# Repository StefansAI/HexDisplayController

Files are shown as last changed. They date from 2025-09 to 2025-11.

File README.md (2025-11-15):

<h1 style="text-align: center;">HexDisplayController</h1>
<h2 style="text-align: center;">A hexadecimal display module for TTL designs</h2>
<br>
<div style="text-align: center;">
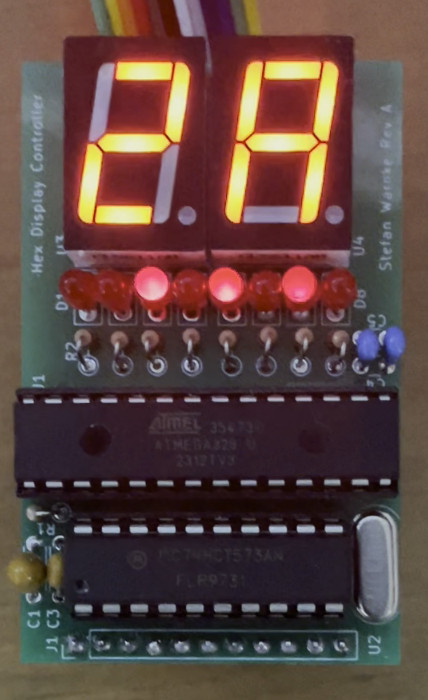
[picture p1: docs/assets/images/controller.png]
  
</div>
<br>
This small PCB reads an 8-bit input and converts the binary code to a 2 digit 7-segment LED as hexadecimals and 8 single bit LEDs. An input register can capture and hold the input data.
<br><br>
<div style="text-align: center;">
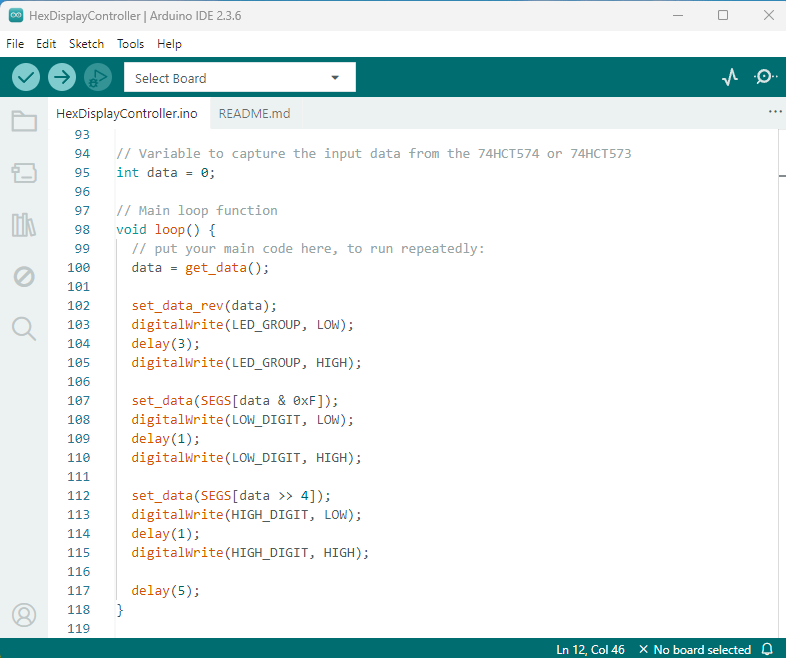
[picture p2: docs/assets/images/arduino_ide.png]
  
</div>
<br>
The processor had been programmed on an Arduino Uno R3 board and then plugged into this controller. 
<br><br>
<div style="text-align: center;">
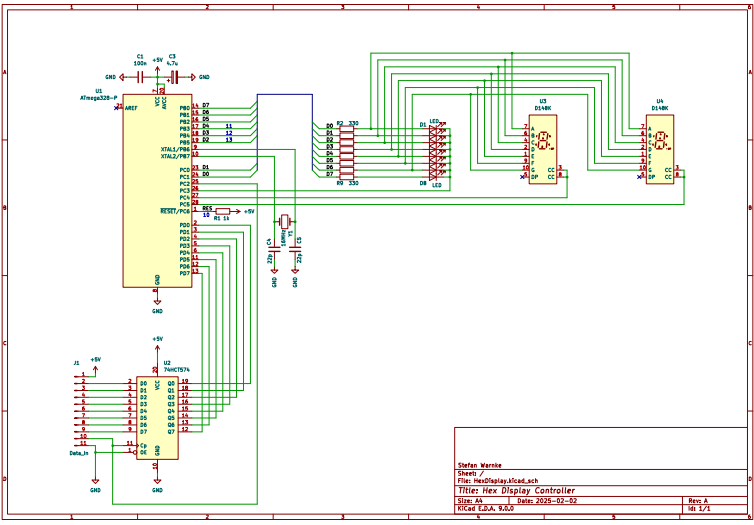
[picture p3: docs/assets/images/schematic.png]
  
</div>
<br>
The schematic and layout are design in KiCad 9 and the design files are included in the repository.
<br><br>
<div style="text-align: center;">
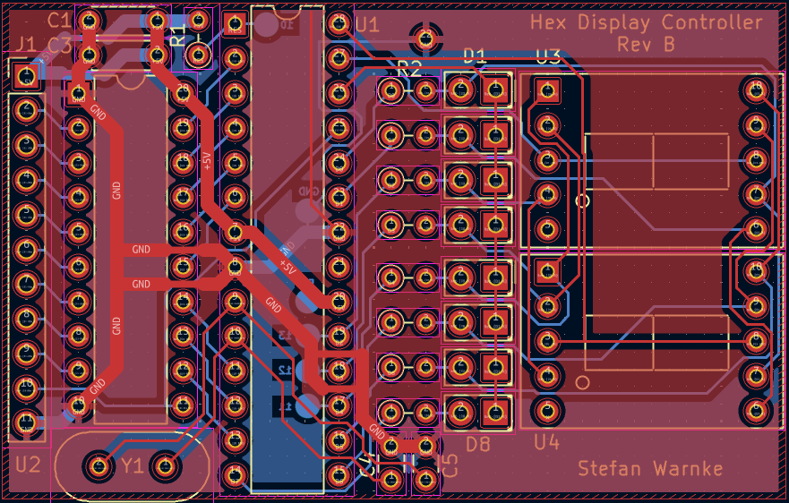
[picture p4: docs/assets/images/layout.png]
  
</div>
<br>
<br><br>
The PCB had been made at <a href="www.PCBway.com">PCBway.</a>

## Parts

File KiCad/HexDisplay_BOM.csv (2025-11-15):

Reference | Value | Datasheet | Footprint | Qty | DNP | OrderInfo
C1 | 100n | ~ | Capacitor_THT:C_Disc_D4.3mm_W1.9mm_P5.00mm | 1 |  | https://www.digikey.com/en/products/detail/kemet/C320C104M5R5TA/3726028
C3 | 4.7u | ~ | Capacitor_THT:C_Disc_D4.3mm_W1.9mm_P5.00mm | 1 |  | https://www.digikey.com/en/products/detail/kyocera-avx/TAP475M010SCS/1472017
C4,C5 | 22p | ~ | Capacitor_THT:C_Disc_D3.0mm_W1.6mm_P2.50mm | 2 |  | https://www.digikey.com/en/products/detail/tdk-corporation/FG28C0G1H220JNT06/5803099
D1,D8 | LED | ~ | LED_THT:LED_D2.0mm_W4.8mm_H2.5mm_FlatTop | 2 |  | https://www.digikey.com/en/products/detail/w%C3%BCrth-elektronik/151031SS04000/4489979
D2,D3,D4,D5,D6,D7 | ~ | ~ | LED_THT:LED_D2.0mm_W4.8mm_H2.5mm_FlatTop | 6 |  | https://www.digikey.com/en/products/detail/w%C3%BCrth-elektronik/151031SS04000/4489979
J1 | Data_In | ~ | Connector_PinHeader_2.54mm:PinHeader_1x11_P2.54mm_Vertical | 1 |  | https://www.digikey.com/en/products/detail/harwin-inc/M20-9771146/3920928
R1,R2,R3,R4,R5,R6,R7,R8,R9 | 1k | ~ | Resistor_THT:R_Axial_DIN0204_L3.6mm_D1.6mm_P2.54mm_Vertical | 9 |  | https://www.digikey.com/en/products/detail/stackpole-electronics-inc/CF18JT1K00/1741612
U1 | ATmega328-P | http://ww1.microchip.com/downloads/en/DeviceDoc/ATmega328_P%20AVR%20MCU%20with%20picoPower%20Technology%20Data%20Sheet%2040001984A.pdf | Package_DIP:DIP-28_W7.62mm | 1 |  | https://www.digikey.com/en/products/detail/microchip-technology/ATMEGA328-PU/2271026
U2 | 74HCT574 | http://www.ti.com/lit/gpn/sn74HCT574 | Package_DIP:DIP-20_W7.62mm | 1 |  | https://www.digikey.com/en/products/detail/texas-instruments/CD74HCT574E/38721
U3,U4 | D148K | https://ia800903.us.archive.org/24/items/CTKD1x8K/Cromatek%20D168K.pdf | Display_7Segment:D1X8K | 2 |  | https://www.amazon.com/dp/B07GTQWF4R?ref=ppx_yo2ov_dt_b_fed_asin_title&th=1
Y1 | 16MHz | ~ | Crystal:Crystal_HC49-U_Vertical | 1 |  | https://www.digikey.com/en/products/detail/yic/16M20P2-49US/15648595
 | 1 | DIP-20_W7.62mm_Socket |  |  |  | https://www.digikey.com/en/products/detail/on-shore-technology-inc/ED20DT/4147598
 | 1 | DIP-28_W7.62mm_Socket |  |  |  | https://www.digikey.com/en/products/detail/on-shore-technology-inc/ED281DT/4147600

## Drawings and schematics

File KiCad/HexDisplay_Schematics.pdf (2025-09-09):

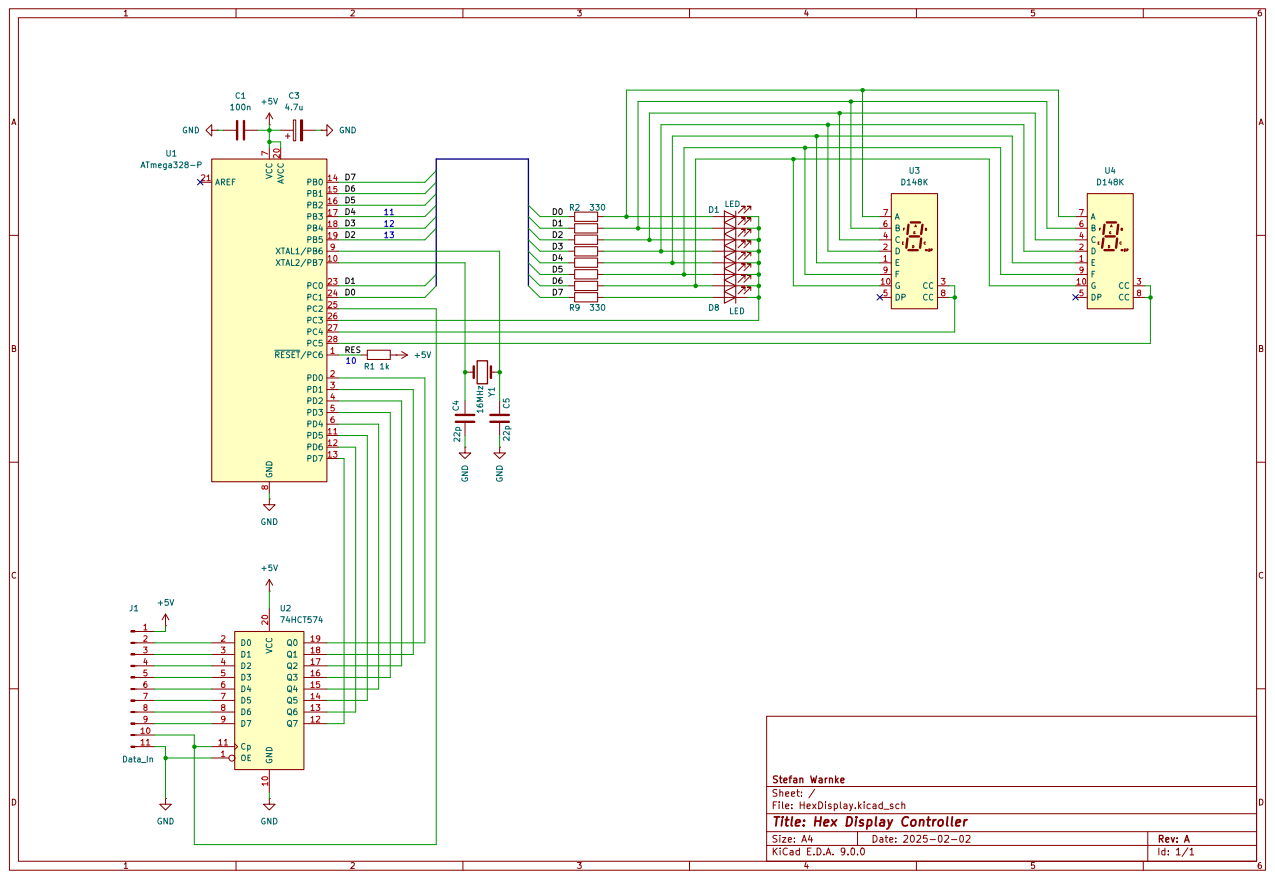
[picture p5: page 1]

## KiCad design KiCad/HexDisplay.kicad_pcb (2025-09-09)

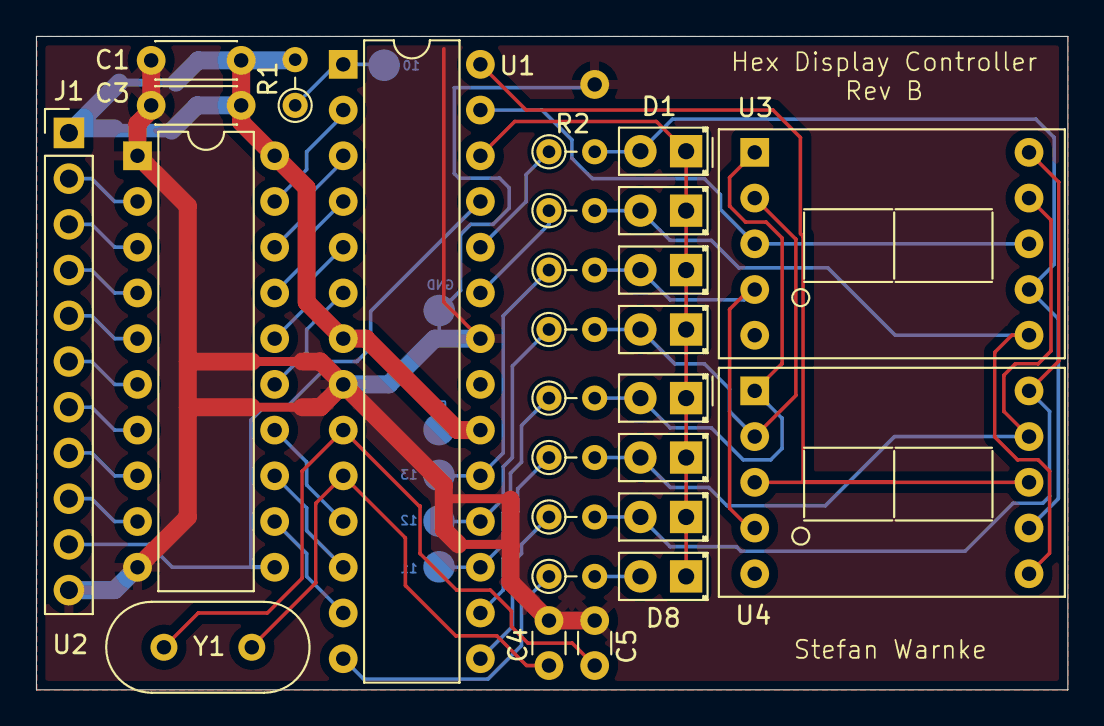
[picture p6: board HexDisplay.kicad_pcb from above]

Board: 2 copper layers, 57.3 x 36.3 mm, 27 parts (0 on the bottom side), 41 nets.

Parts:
C1: 100n; C_Disc_D4.3mm_W1.9mm_P5.00mm
C3: 4.7u; C_Disc_D4.3mm_W1.9mm_P5.00mm
C4, C5: 22p; C_Disc_D3.0mm_W1.6mm_P2.50mm
D1, D8: LED; LED_D2.0mm_W4.8mm_H2.5mm_FlatTop
D2, D3, D4, D5, D6, D7: LED_D2.0mm_W4.8mm_H2.5mm_FlatTop
J1: Data_In; PinHeader_1x11_P2.54mm_Vertical
R1: 1k; R_Axial_DIN0204_L3.6mm_D1.6mm_P2.54mm_Vertical
R2, R3, R4, R5, R6, R7, R8, R9: 330; R_Axial_DIN0204_L3.6mm_D1.6mm_P2.54mm_Vertical
U1: ATmega328-P; DIP-28_W7.62mm
U2: 74HCT574; DIP-20_W7.62mm
U3, U4: D148K; D1X8K
Y1: 16MHz; Crystal_HC49-U_Vertical

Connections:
+5V: C1.2, C3.1, J1.1, R1.2, U1.7 (VCC), U1.20 (AVCC), U2.20 (VCC)
/D0: R2.1, U1.24 (PC1)
/D1: R3.1, U1.23 (PC0)
/D2: R4.1, U1.19 (PB5)
/D3: R5.1, U1.18 (PB4)
/D4: R6.1, U1.17 (PB3)
/D5: R7.1, U1.16 (PB2)
/D6: R8.1, U1.15 (PB1)
/D7: R9.1, U1.14 (PB0)
/RES: R1.1, U1.1 (~RESET/PC6)
GND: C1.1, C3.2, C4.2, C5.2, J1.11, U1.8 (GND), U1.22 (GND), U2.1 (OE), U2.10 (GND)
unnamed: D1.2 (A), R2.2, U3.7 (A), U4.7 (A)
unnamed: D1.1 (K), D2.1 (K), D3.1 (K), D4.1 (K), D5.1 (K), D6.1 (K), D7.1 (K), D8.1 (K), U1.26 (PC3)
unnamed: D2.2 (A), R3.2, U3.6 (B), U4.6 (B)
unnamed: D3.2 (A), R4.2, U3.4 (C), U4.4 (C)
unnamed: D4.2 (A), R5.2, U3.2 (D), U4.2 (D)
unnamed: D5.2 (A), R6.2, U3.1 (E), U4.1 (E)
unnamed: D6.2 (A), R7.2, U3.9 (F), U4.9 (F)
unnamed: D7.2 (A), R8.2, U3.10 (G), U4.10 (G)
unnamed: D8.2 (A), R9.2
unnamed: J1.2, U2.2 (D0)
unnamed: J1.3, U2.3 (D1)
unnamed: J1.4, U2.4 (D2)
unnamed: J1.5, U2.5 (D3)
unnamed: J1.6, U2.6 (D4)
unnamed: J1.7, U2.7 (D5)
unnamed: J1.8, U2.8 (D6)
unnamed: J1.9, U2.9 (D7)
unnamed: J1.10, U1.25 (PC2), U2.11 (Cp)
unnamed: U1.27 (PC4), U3.3 (CC), U3.8 (CC)
unnamed: U1.28 (PC5), U4.3 (CC), U4.8 (CC)
unnamed: U1.2 (PD0), U2.19 (Q0)
unnamed: U1.3 (PD1), U2.18 (Q1)
unnamed: U1.4 (PD2), U2.17 (Q2)
unnamed: U1.5 (PD3), U2.16 (Q3)
unnamed: U1.6 (PD4), U2.15 (Q4)
unnamed: U1.11 (PD5), U2.14 (Q5)
unnamed: U1.12 (PD6), U2.13 (Q6)
unnamed: U1.13 (PD7), U2.12 (Q7)
unnamed: C5.1, U1.9 (XTAL1/PB6), Y1.2
unnamed: C4.1, U1.10 (XTAL2/PB7), Y1.1

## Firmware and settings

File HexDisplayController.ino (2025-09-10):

// ================================================
//
// SPDX-FileCopyrightText: 2025 Stefan Warnke
//
// SPDX-License-Identifier: BeerWare
//
//=================================================
//
// File:  HexDisplayController
// 
// Periodically read in the 8-bit input data and
// display the bits and the 2 digit hex code.
//
//=================================================

// Input data pin definition array
const int DIN[8] = { 0, 1, 2, 3, 4, 5, 6, 7 }; 
// Output data pin definition array
const int DOUT[8] = { 15, 14, 13, 12, 11, 10, 9, 8 };
// 7 Segment definitions for displaying the numbers 0 to 15 
const int SEGS[16] = { 0x3F, 0x06, 0x5B, 0x4F, 0x66, 0x6D, 0x7D, 0x07, 0x7F, 0x6F, 0x77, 0x7C, 0x39, 0x5E, 0x79, 0x71};

// Pin definition for the latch pull-up of a 74HCT573 data input chip, it does not have any impact if the chip is a 74HCT574 with driven clock
const int PULL_UP = 16;
// Common cathode pin of the single bit LED group
const int LED_GROUP = 17;
// Common cathode pin of the higher digit 7 segment display
const int HIGH_DIGIT = 18;
// Common cathode pin of the lower digit 7 segment display
const int LOW_DIGIT = 19;

// Query all data input bits and return the 8bit data value read from the input chip.
int get_data()
{
  int result=0;
  for (int i=0; i<8; i++)
  {
    int value = digitalRead(DIN[i]);
    if (value == HIGH)
      result += 1<<i;    
  }
  return result;
}

// Set the 8 bit data output for the 7 segment LED
void set_data(int value)
{
  for (int i=0; i<8; i++)
  {
    if ((value & 1) == 0)
      digitalWrite(DOUT[i], LOW);
    else
      digitalWrite(DOUT[i], HIGH);
    value >>= 1;
  }
}

// Set the 8 bit data output for the 8 bit LEDs
void set_data_rev(int value)
{
  for (int i=7; i>=0; i--)
  {
    if ((value & 1) == 0)
      digitalWrite(DOUT[i], LOW);
    else
      digitalWrite(DOUT[i], HIGH);
    value >>= 1;
  }
}

// Initialization function called before the loop
void setup() {
  // put your setup code here, to run once:
  pinMode(PULL_UP, INPUT_PULLUP);

  pinMode(LED_GROUP, OUTPUT);
  digitalWrite(LED_GROUP, HIGH);

  pinMode(HIGH_DIGIT, OUTPUT);
  digitalWrite(HIGH_DIGIT, HIGH);

  pinMode(LOW_DIGIT, OUTPUT);
  digitalWrite(LOW_DIGIT, HIGH);

  for (int i=0; i<8; i++)
  {
    pinMode(DIN[i], INPUT);

    pinMode(DOUT[i], OUTPUT);
    digitalWrite(DOUT[i], LOW);
  }
}

// Variable to capture the input data from the 74HCT574 or 74HCT573
int data = 0;

// Main loop function
void loop() {
  // put your main code here, to run repeatedly:
  data = get_data();

  set_data_rev(data);
  digitalWrite(LED_GROUP, LOW);
  delay(3);
  digitalWrite(LED_GROUP, HIGH);

  set_data(SEGS[data & 0xF]);
  digitalWrite(LOW_DIGIT, LOW);
  delay(1);
  digitalWrite(LOW_DIGIT, HIGH);

  set_data(SEGS[data >> 4]);
  digitalWrite(HIGH_DIGIT, LOW);
  delay(1);
  digitalWrite(HIGH_DIGIT, HIGH);

  delay(5);
}

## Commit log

2025-09-09 Initial Check-in
    [HexDisplay-B_Cu.gbr, HexDisplay-B_Mask.gbr, HexDisplay-B_Paste.gbr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]
2025-11-15 Updates of KiCad files and README
    [HexDisplay.kicad_sch, HexDisplay_BOM.csv]
